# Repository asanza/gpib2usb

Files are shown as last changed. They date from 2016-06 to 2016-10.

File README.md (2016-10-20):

# GPIB (IEEE-488) to usb adapter


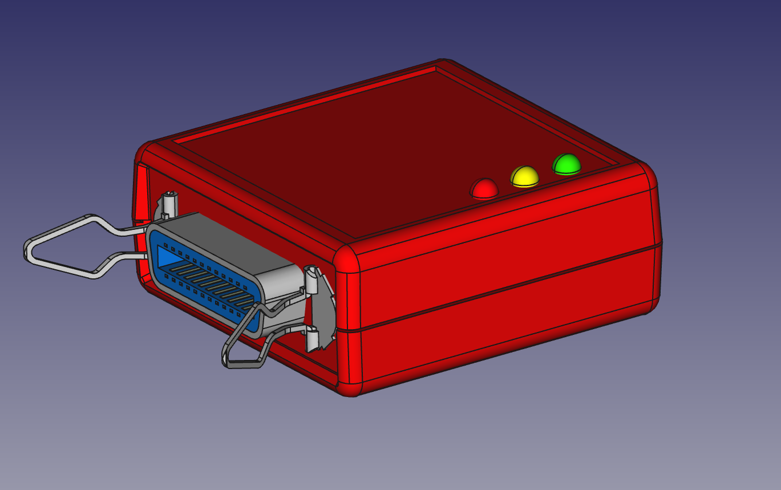
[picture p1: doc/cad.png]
gpib2usb


We live in wonderful times... Now is possible for us to get pretty good but old and used measurement equipment on e-bay, just for a few bucks. Equipment that otherwise would be out of  the hobbist leage, like 6.5 digit multimeters, oscilloscopes, signal generators... just to name a few.

These old equipment often come with a GPIB interface, which allows to control them from a computer with the corresponding GPIB connection. Regretably, computers do not come with GPIB interfaces, and the adapters available are not cheap.

Here comes this little device to rescue. It is a gpib-to-usb adapter which after connected to the computer via the almighty usb port, it presents itself as a serial port and allows to send GPIB commands to connected GPIB devices.

For now is yet a work in progress.

# Getting Started

The device presents itself as a serial port. The commands are the same as the similar device sold by [Prologix LLC](http://prologix.biz/gpib-usb-controller.html), but compatibility is not guaranteed.

| Command	 | Description |
|---|---|
|++addr 0-31|	Tell controller which device to address|
|++addr	| Query currently configured device address
|++clr	| This command sends the Selected Device Clear (SDC) message to the currently specified GPIB address. Please consult the programming manual for details on how a particular instrument responds to this message.
|++eoi 0/1|	Enable (1) or disable (0) EOI with last byte. Default is 0. This command enables or disables the assertion of the EOI signal with the last character of any command sent over GPIB port. Some instruments require EOI signal to be asserted in order to properly detect the end of a command.
|++eoi	|Query current EOI setting
|++eos 0/1/2/3	|EOS terminator — 0:CR+LF, 1:CR, 2:LF, 3:None. Default is 0. This command specifies GPIB termination characters. When data from host is received over USB, all non-escaped LF, CR and ESC characters are removed and GPIB terminators, as specified by this command, are appended before sending the data to instruments. This command does not affect data from instruments received over GPIB port.|
|++eos	|Query current EOS setting
|++ifc	|Issue interface clear. This command asserts GPIB IFC signal for 150 microseconds making the gpib2usb controller the Controller-In-Charge on the GPIB bus.
|++loc	|Return device to local mode
|++read  [eoi/char]| This command can be used to read data from an instrument until: EOI is detected or timeout expires, or A specified character is read or timeout expires, or Timeout expires. Timeout is set using the read_tmo_ms command and applies to inter-character delay, i.e., the delay since the last character was read. Timeout is not be confused with the total time for which data is read. |
|++read_tmo_ms [1-3000]| This command specifies the timeout value, in milliseconds, to be used in the read command and spoll command. Timeout may be set to any value between 1 and 3000 milliseconds.|
|++spoll	|Read status byte by serial polling the device
|++srq	|Query status of SRQ line. 0: Not asserted, 1:Asserted
|++trg	|Issue device trigger
|++ver	|Query GPIB-USB controller version
|++help	|Print help about commands

To send binary data to instruments following characters must be escaped by preceding them with an ESC character:
CR (ASCII 13), LF (ASCII 10), ESC (ASCII 27), ‘+’ (ASCII 43)

# Contributing

# Know issues

## Disable modem manager in linux.

In order to detect new devices, modem manager issues two AT commands to each new ACM device detected. This blocks the serial port and causes it to be unavailable the first seconds. This is somewhat annoying. Fortunately it is possible to disable this behaviour. You need to create a new file:

```
/etc/udev/rules.d/77-mm-usb-device-blacklist.rules
```
and put following content in it:

```
with content:
# gpib2usb converter
ATTRS{idVendor}=="1209", ATTRS{idProduct}=="0001", ENV{ID_MM_DEVICE_IGNORE}="1"
```

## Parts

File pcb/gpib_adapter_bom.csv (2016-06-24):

Id | Designator | Package | Quantity | Designation | Supplier and ref
1 | P5 | gpib_conn_male | 1 | GPIB
2 | C2,C3 | C_0805 | 2 | 18p
3 | C7,C8,C4,C5 | C_0805 | 4 | 100n
4 | R1 | R_0805 | 1 | R
5 | R2,R3 | R_0805 | 2 | 22
6 | R4,R5,R6 | R_0805 | 3 | 470
7 | U1 | SOIC-20_7.5x12.8mm_Pitch1.27mm | 1 | SN75160
8 | U2 | SOIC-20_7.5x12.8mm_Pitch1.27mm | 1 | SN75161
9 | P1 | TC2030-NL_SMALL | 1 | TC2030-MCP
10 | D4 | PRTR5V0U2X | 1 | PRTR5V0U2X
11 | F1 | R_1210 | 1 | F_Small
12 | D3,D1,D2 | LED-5MM | 3 | PWR
13 | U3 | TQFP-44_10x10mm_Pitch0.8mm | 1 | PIC18(L)F4550-I/PT
14 | X1 | Crystal_SMD_5032_4Pads | 1 | 8MHz
15 | C1 | C_0805 | 1 | 1u
16 | C6,C9 | C_0805 | 2 | 10n
17 | C10 | C_1206 | 1 | C
18 | R7 | R_1206 | 1 | R
19 | P2 | USB_B | 1 | USB

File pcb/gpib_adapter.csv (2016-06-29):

Source: | /home/diego/Projects/gpib2usb/pcb/gpib_adapter.sch
Date: | Mi 29 Jun 2016 20:20:03 CEST
Tool: | Eeschema 4.1.0-alpha+201606241232+6946~45~ubuntu16.04.1-product
Generator: | /home/diego/Electronics/Libraries/scripts/bom_csv_grouped_by_value_with_fp.py
Component Count: | 29
Ref | Qnty | Value | Cmp name | Footprint | Description | Vendor
C1, | 1 | 1u | C | Capacitors_SMD:C_0805 | Unpolarized capacitor
C3, C2, | 2 | 18p | C | Capacitors_SMD:C_0805 | Unpolarized capacitor
C6, C9, | 2 | 10n | C | Capacitors_SMD:C_0805 | Unpolarized capacitor
C7, C8, C4, C5, | 4 | 100n | C | Capacitors_SMD:C_0805 | Unpolarized capacitor
C10, | 1 | C | C | Capacitors_SMD:C_1206 | Unpolarized capacitor
D1, D2, D3, | 3 | PWR | LED-RESCUE-gpib_adapter | LEDs:LED-5MM
D4, | 1 | PRTR5V0U2X | PRTR5V0U2X | esd_protection:PRTR5V0U2X
F1, | 1 | F_Small | F_Small | Resistors_SMD:R_1210 | Fuse
P1, | 1 | TC2030-MCP | TC2030-MCP | tagconnect:TC2030-NL_SMALL
P2, | 1 | USB | CONN_5 | Connect:USB_B
P5, | 1 | GPIB | CONN_12X2 | gpib_conn_male:gpib_conn_male
R1, | 1 | R | R-RESCUE-gpib_adapter | Resistors_SMD:R_0805
R2, R3, | 2 | 22 | R | Resistors_SMD:R_0805 | Resistor
R4, R5, R6, | 3 | 470 | R | Resistors_SMD:R_0805 | Resistor
R7, | 1 | R | R | Resistors_SMD:R_1206 | Resistor
U1, | 1 | SN75160 | SN75160 | Housings_SOIC:SOIC-20_7.5x12.8mm_Pitch1.27mm
U2, | 1 | SN75161 | SN75161 | Housings_SOIC:SOIC-20_7.5x12.8mm_Pitch1.27mm
U3, | 1 | PIC18(L)F4550-I/PT | PIC18(L)F4550-I/PT | Housings_QFP:TQFP-44_10x10mm_Pitch0.8mm | PIC18(L)F4455, 24K Flash, 2K SRAM, 256 EEPROM, USB, nanoWatt XLP, TQFP44
X1, | 1 | 8MHz | CRYSTAL_SMD | Crystals:Crystal_SMD_5032_4Pads

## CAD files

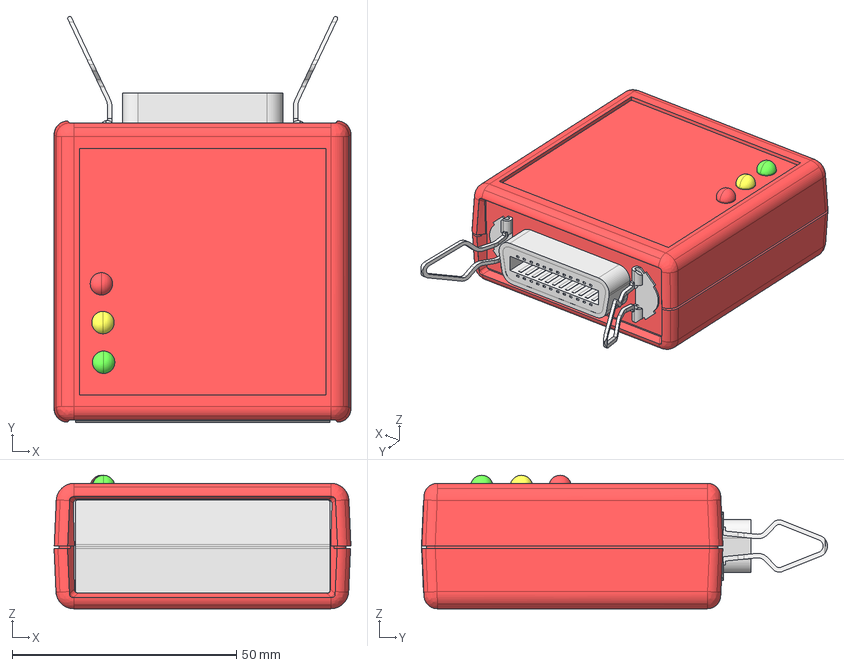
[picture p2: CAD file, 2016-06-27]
pcb/cad/assembly.fcstd
66.3 x 90.6 x 29.8 mm
_593K_BOTTOM
_593K_Endplate
_593K_Top
_593K_L_Contoured_Endplate
Board_outline
LED 5mm
LED 5mm003
LED 5mm006
Centronics

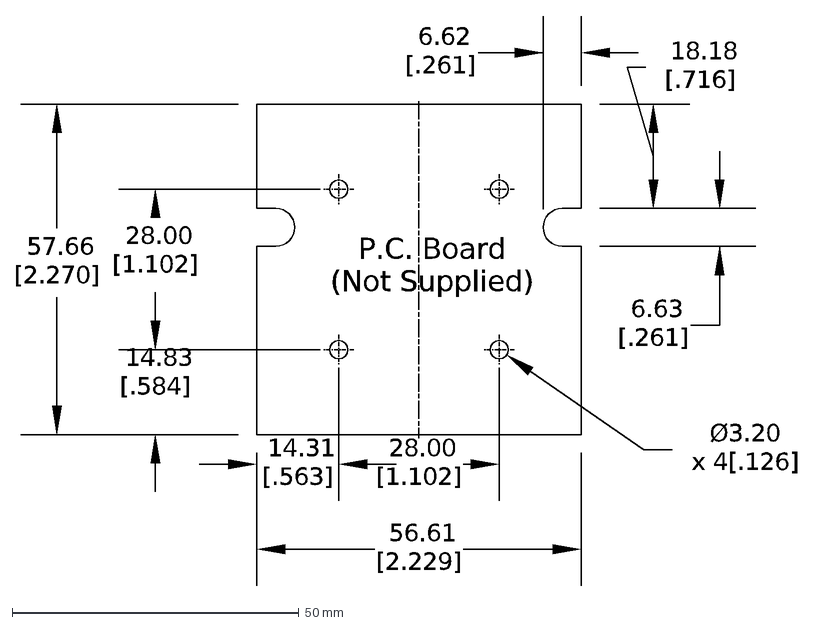
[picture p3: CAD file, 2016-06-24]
pcb/floorplan.dxf
28.00 [1.102]
56.61 [2.229]
14.31 [.563]
57.66 [2.270]
18.18 [.716]
6.63 [.261]
14.83 [.584]
6.62 [.261]
Ø3.20 x 4[.126]
P.C. Board (Not Supplied)

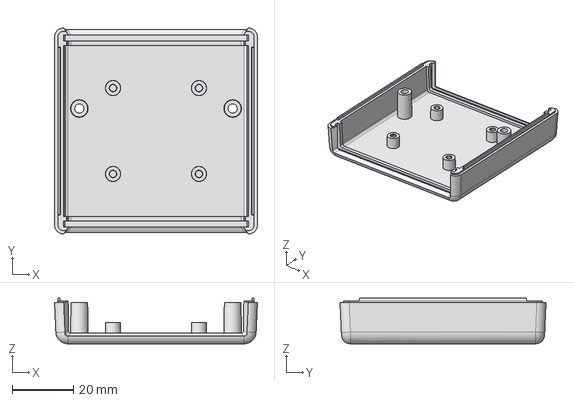
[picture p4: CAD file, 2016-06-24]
pcb/cad/1593K BOTTOM.stp
66.2 x 67.2 x 14.9 mm

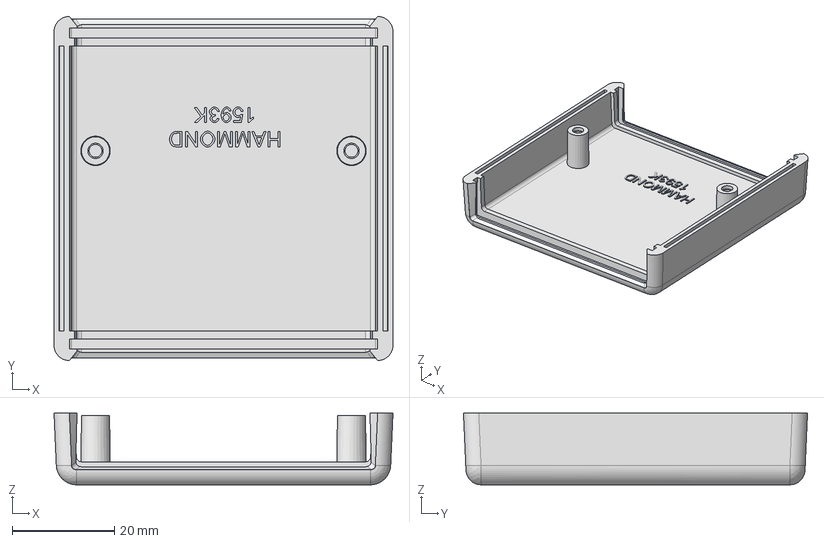
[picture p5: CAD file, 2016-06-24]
pcb/cad/1593K Top.stp
66.2 x 67.2 x 14.0 mm

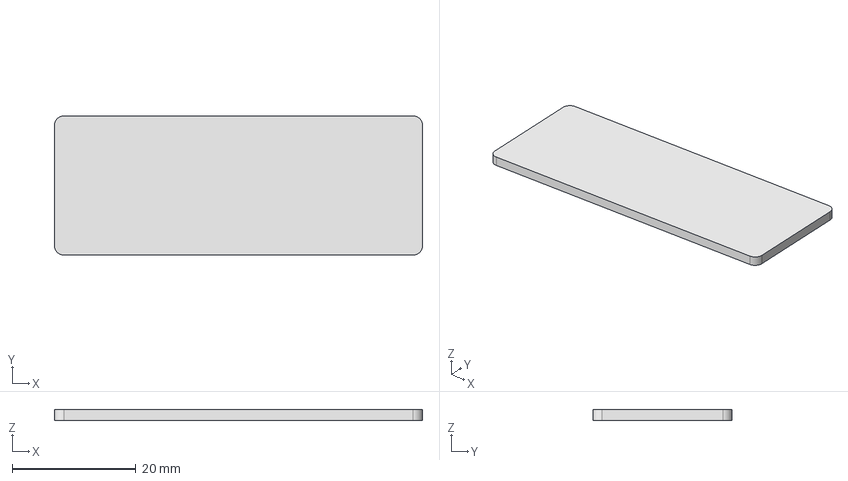
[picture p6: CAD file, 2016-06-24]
pcb/cad/1593K Endplate.stp
59.5 x 22.5 x 1.70 mm

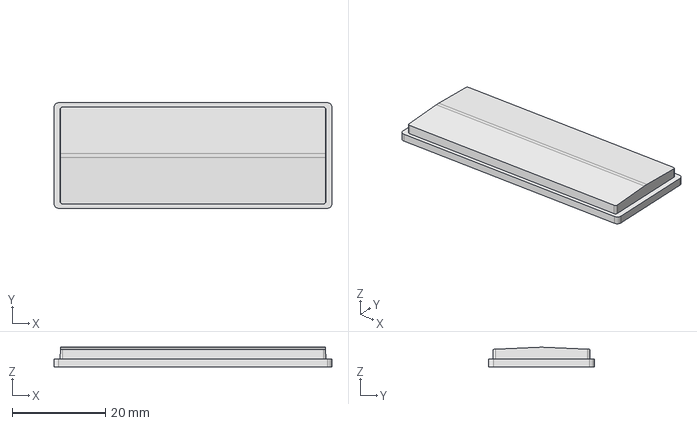
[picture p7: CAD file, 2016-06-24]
pcb/cad/1593K-L Contoured Endplate.stp
59.5 x 22.6 x 4.19 mm

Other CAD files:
pcb/cad/1593K.dwg
pcb/cad/1593K BOTTOM.igs
pcb/cad/1593K Endplate.igs
pcb/cad/1593K Top.igs
pcb/cad/1593K-L Contoured Endplate.igs

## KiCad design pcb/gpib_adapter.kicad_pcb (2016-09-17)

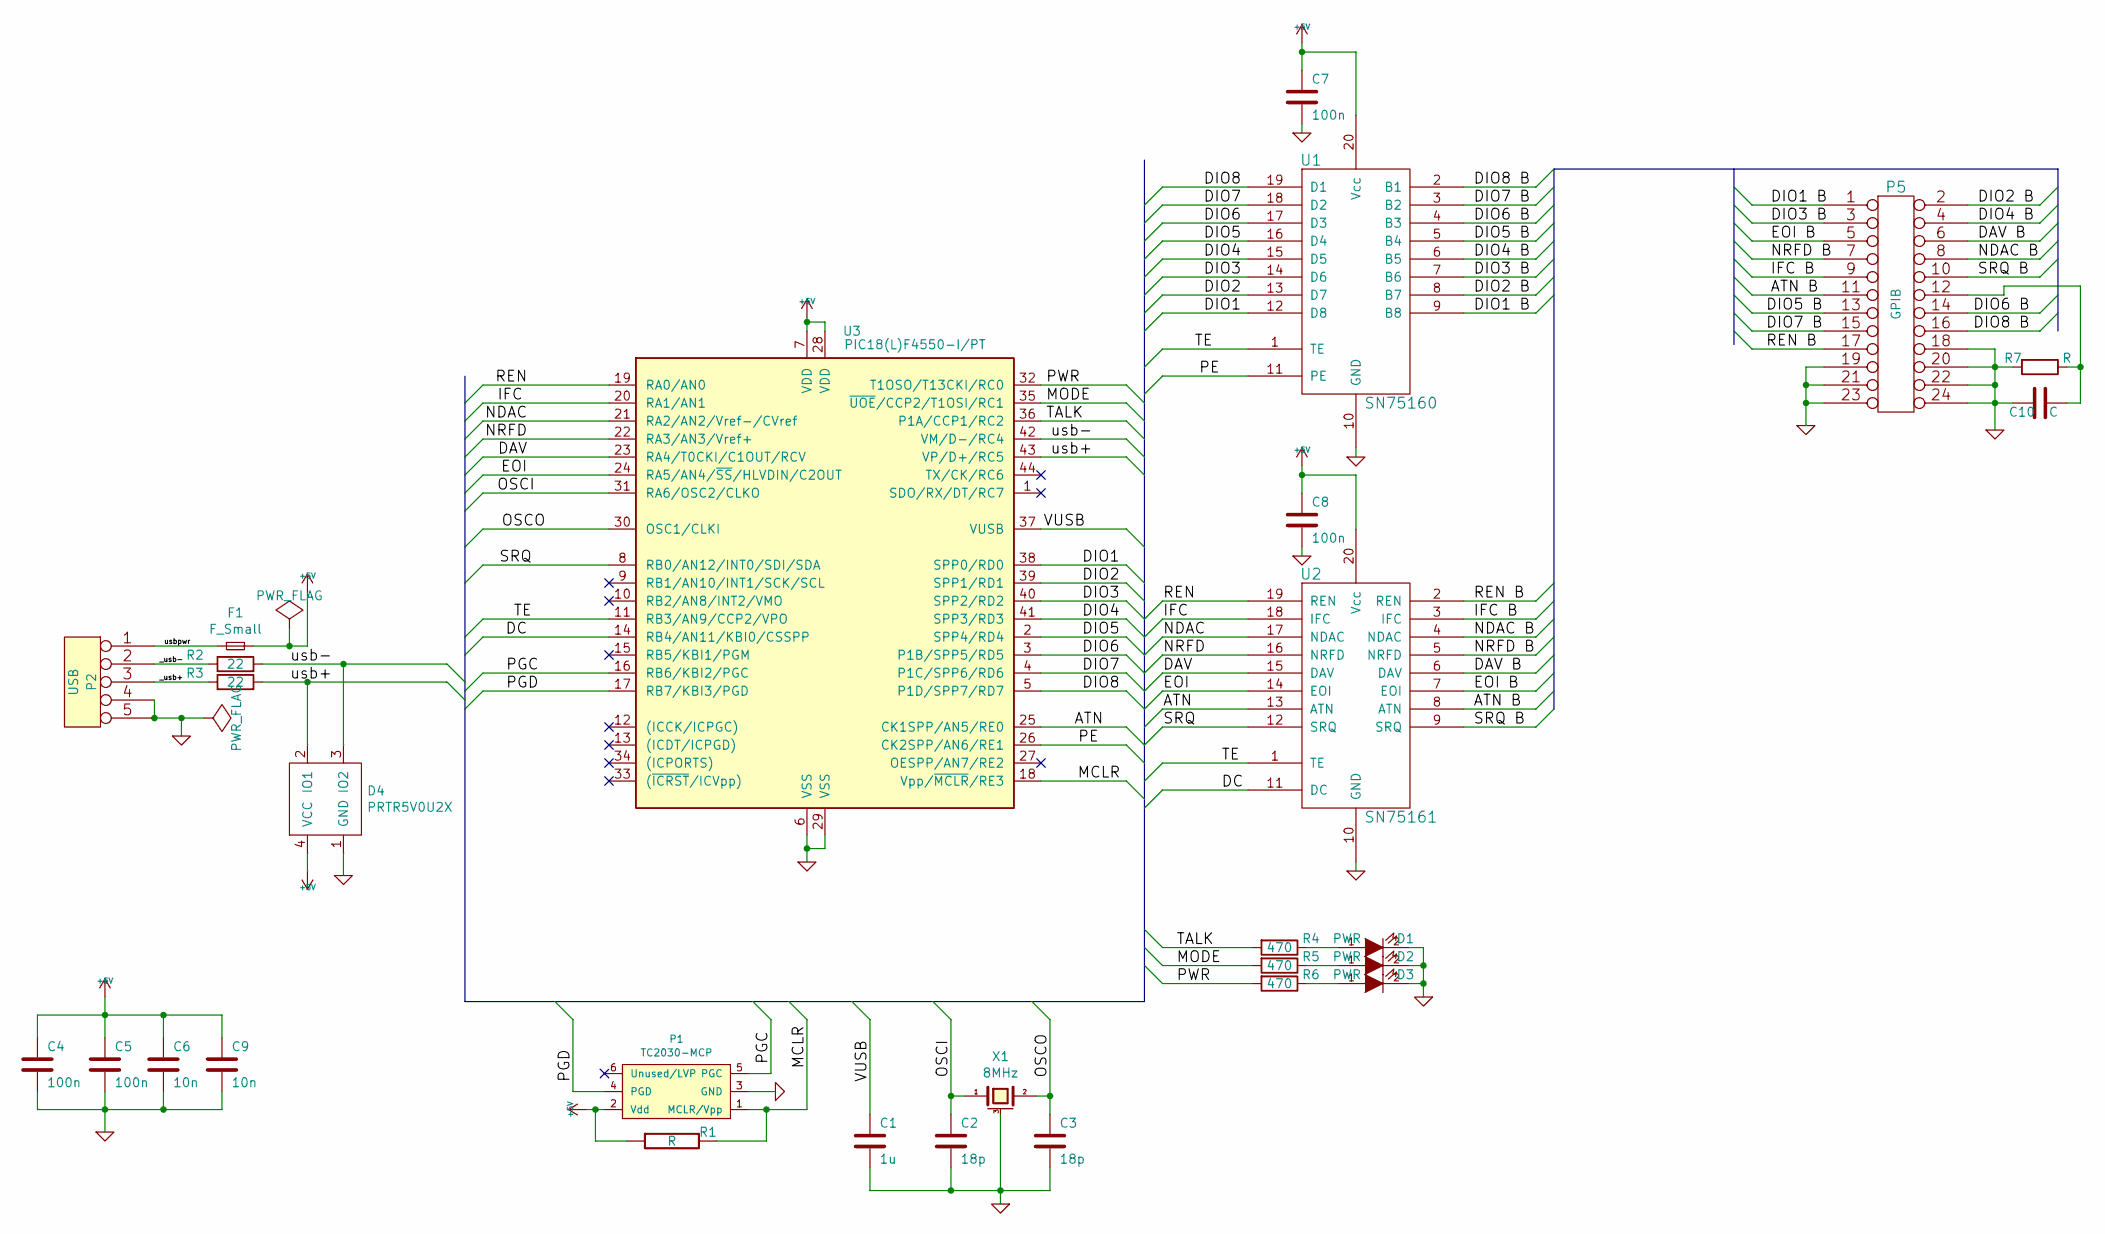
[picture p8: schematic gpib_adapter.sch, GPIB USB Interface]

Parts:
C1: 1u; C_0805
C2, C3: 18p; C_0805
C4, C5, C7, C8: 100n; C_0805
C6, C9: 10n; C_0805
C10: C; C_1206
D1, D2, D3: PWR; LED-5MM
D4: PRTR5V0U2X
F1: F_Small; R_1210
P1: TC2030-MCP; TC2030-NL_SMALL
P2: USB; USB_B
P5: GPIB; gpib_conn_male; Digikey 1024RFA-ND
R1: R; R_0805
R2, R3: 22; R_0805
R4, R5, R6: 470; R_0805
R7: R; R_1206
U1: SN75160; SOIC-20_7.5x12.8mm_Pitch1.27mm
U2: SN75161; SOIC-20_7.5x12.8mm_Pitch1.27mm
U3: PIC18(L)F4550-I/PT; TQFP-44_10x10mm_Pitch0.8mm
X1: 8MHz; Crystal_SMD_5032_4Pads

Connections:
+5V: C4.1, C5.1, C6.1, C7.1, C8.1, C9.1, D4.4 (VCC), F1.2, P1.2 (Vdd), R1.1, U1.20 (Vcc), U2.20 (Vcc), U3.7 (VDD), U3.28 (VDD)
/ATN: U2.13 (ATN), U3.25 (CK1SPP/AN5/RE0)
/ATN B: P5.11, U2.8 (ATN)
/DAV: U2.15 (DAV), U3.23 (RA4/T0CKI/C1OUT/RCV)
/DAV B: P5.6, U2.6 (DAV)
/DC: U2.11 (DC), U3.14 (RB4/AN11/KBI0/CSSPP)
/DIO1: U1.12 (D8), U3.38 (SPP0/RD0)
/DIO1 B: P5.1, U1.9 (B8)
/DIO2: U1.13 (D7), U3.39 (SPP1/RD1)
/DIO2 B: P5.2, U1.8 (B7)
/DIO3: U1.14 (D6), U3.40 (SPP2/RD2)
/DIO3 B: P5.3, U1.7 (B6)
/DIO4: U1.15 (D5), U3.41 (SPP3/RD3)
/DIO4 B: P5.4, U1.6 (B5)
/DIO5: U1.16 (D4), U3.2 (SPP4/RD4)
/DIO5 B: P5.13, U1.5 (B4)
/DIO6: U1.17 (D3), U3.3 (P1B/SPP5/RD5)
/DIO6 B: P5.14, U1.4 (B3)
/DIO7: U1.18 (D2), U3.4 (P1C/SPP6/RD6)
/DIO7 B: P5.15, U1.3 (B2)
/DIO8: U1.19 (D1), U3.5 (P1D/SPP7/RD7)
/DIO8 B: P5.16, U1.2 (B1)
/EOI: U2.14 (EOI), U3.24 (RA5/AN4/~SS~/HLVDIN/C2OUT)
/EOI B: P5.5, U2.7 (EOI)
/IFC: U2.18 (IFC), U3.20 (RA1/AN1)
/IFC B: P5.9, U2.3 (IFC)
/MCLR: P1.1 (MCLR/Vpp), R1.2, U3.18 (Vpp/~MCLR~/RE3)
/MODE: R5.2, U3.35 (~UOE~/CCP2/T1OSI/RC1)
/NDAC: U2.17 (NDAC), U3.21 (RA2/AN2/Vref-/CVref)
/NDAC B: P5.8, U2.4 (NDAC)
/NRFD: U2.16 (NRFD), U3.22 (RA3/AN3/Vref+)
/NRFD B: P5.7, U2.5 (NRFD)
/OSCI: C2.1, U3.31 (RA6/OSC2/CLKO), X1.1
/OSCO: C3.1, U3.30 (OSC1/CLKI), X1.2
/PE: U1.11 (PE), U3.26 (CK2SPP/AN6/RE1)
/PGC: P1.5 (PGC), U3.16 (RB6/KBI2/PGC)
/PGD: P1.4 (PGD), U3.17 (RB7/KBI3/PGD)
/PWR: R6.2, U3.32 (T1OSO/T13CKI/RC0)
/REN: U2.19 (REN), U3.19 (RA0/AN0)
/REN B: P5.17, U2.2 (REN)
/SRQ: U2.12 (SRQ), U3.8 (RB0/AN12/INT0/SDI/SDA)
/SRQ B: P5.10, U2.9 (SRQ)
/TALK: R4.2, U3.36 (P1A/CCP1/RC2)
/TE: U1.1 (TE), U2.1 (TE), U3.11 (RB3/AN9/CCP2/VPO)
/VUSB: C1.1, U3.37 (VUSB)
/_usb+: P2.3, R3.1
/_usb-: P2.2, R2.1
/usb+: D4.2 (IO1), R3.2, U3.43 (VP/D+/RC5)
/usb-: D4.3 (IO2), R2.2, U3.42 (VM/D-/RC4)
/usbpwr: F1.1, P2.1
GND: C1.2, C2.2, C3.2, C4.2, C5.2, C6.2, C7.2, C8.2, C9.2, C10.2, D1.2 (K), D2.2 (K), D3.2 (K), D4.1 (GND), P1.3 (GND), P2.4, P2.5, P5.18, P5.19, P5.20, P5.21, P5.22, P5.23, P5.24, R7.2, U1.10 (GND), U2.10 (GND), U3.6 (VSS), U3.29 (VSS), X1.3 (case)
unnamed: C10.1, P5.12, R7.1
unnamed: D1.1 (A), R4.1
unnamed: D2.1 (A), R5.1
unnamed: D3.1 (A), R6.1

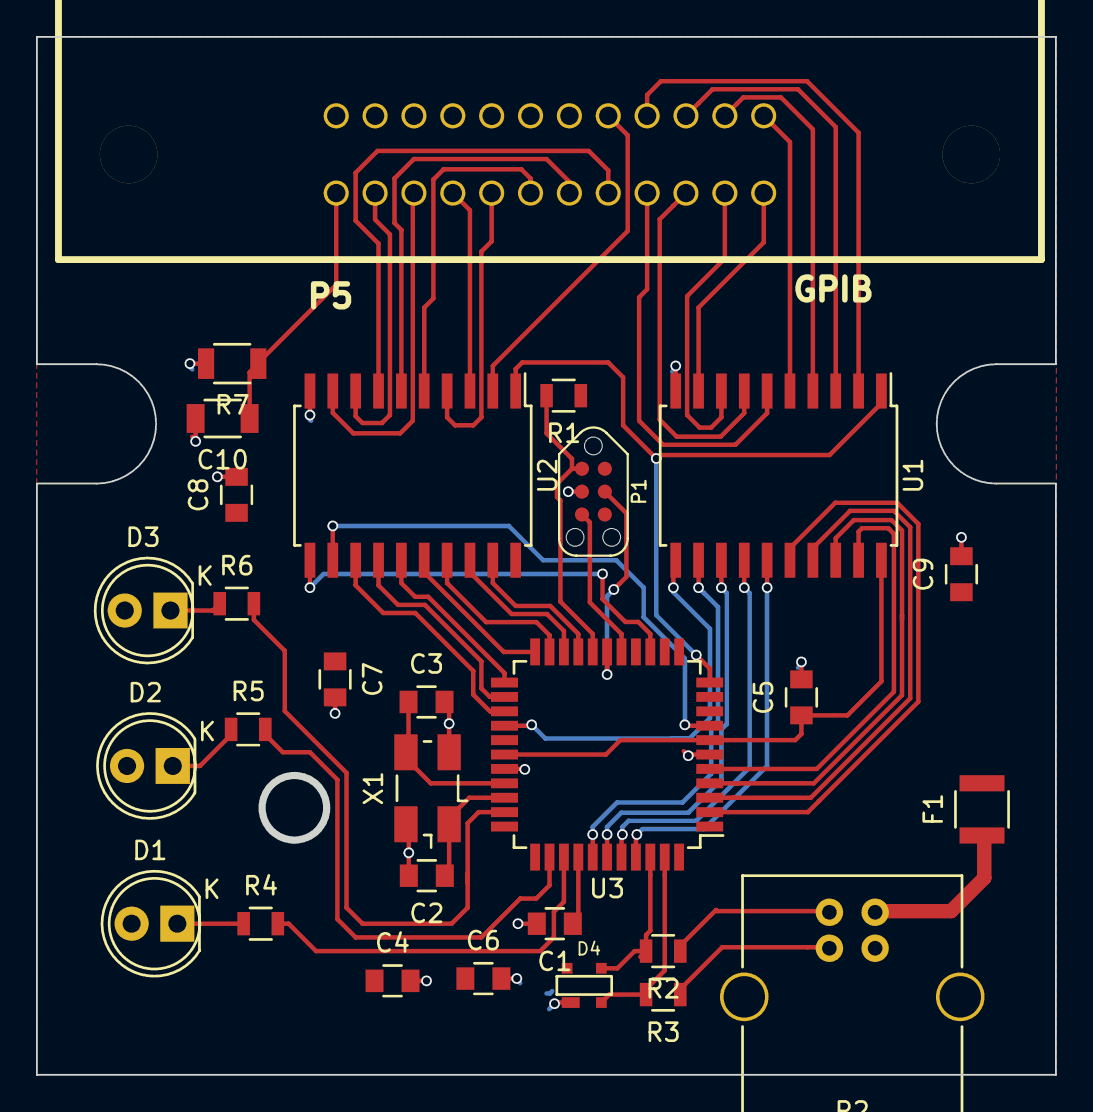
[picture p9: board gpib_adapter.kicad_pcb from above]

Board: 2 copper layers, 56.6 x 57.7 mm, 29 parts (0 on the bottom side), 55 nets.

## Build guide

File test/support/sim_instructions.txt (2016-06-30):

device pic18f4550
hwtool sim
set oscillator.frequency 	8
set oscillator.frequencyunit 	Mega
set oscillator.rcfrequency  	250
set oscillator.rcfrequencyunit 	Kilo
set uart1io.uartioenabled	true
set uart1io.output		file
set uart1io.outputfile		test/support/out.txt
set system.disableerrormsg 	true
set breakoptions.coreerrors 	Break
set breakoptions.peripheralerrors Break
set breakoptions.wdtwarnings 	Break
set breakoptions.peripheralwarnings Break

program build/test/TestBuild.elf

run
break unity.c:1168
wait 5000
quit

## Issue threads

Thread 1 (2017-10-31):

Produced no output to $stdout.

Neroone, 2017-10-31:
Hi,

I am new to PIC microcontrollers and I am trying to write unit tests for PIC18F86K22.  I use a xc8 compiler. I found your project using a PIC and xc8 compiler while browsing. I am trying to use ceedling and I have tried to use some of your files and added a simple c file and test file. When I run ceedling test:all on Ubuntu 16.04, I get the following error.
ERROR: Test executable "test_lights.out" failed.
> Produced no output to $stdout.
> And exited with status: [0] (count of failed tests).
> This is often a symptom of a bad memory access in source or test code. and no out.txt is created. Also, in simlog.txt I notice that the program has failed. Can you please help me figure out why I get this error.
Thanks.
[testproject.zip](https://github.com/asanza/gpib2usb/files/1431758/testproject.zip)

asanza, 2017-10-31:
Hi,
I think you test are compiling just fine, they are just not being executed.

Looking into the log of the test fixture (test/support/simlog.txt), it seems that your simulator is not loading the firmware, but I cannot figure out why.
```
program build/test/TestBuild.elf
Programming target...
Program failed.
```
Could you just check that the TestBuild.elf file exists, and try to load it manually in the mplab simulator,
may be give you more clues.

Neroone, 2017-11-01:
Hi,
The testBuild.elf does exist and I tried running from the mdb command line. The program was not executed.

I tried changing the .elf to .hex in sim_instructions.txt and the out.txt was created this time(with some garbled letters).
and simlog.txt had the following
program build/test/TestBuild.hex
Programming target...
Program succeeded.
run

break unity.c:1168
unity.c:1168 could not be resolved to an address
wait 5000
quit
Stop at
	address:0xf0e2

I am still getting the error from ceedling:test all

ERROR: Test executable "test_lights.out" failed.
> Produced no output to $stdout.
> And exited with status: [0] (count of failed tests).
> This is often a symptom of a bad memory access in source or test code.

Any suggestions?

asanza, 2017-11-04:
Hi,
Yes a couple of points:

1. break unity.c:1168 was an ugly hack in order to exit the simulator when unity exits.
I couldn't figure out other way.  You can look where is the exit line in your unity.c and
locate the breakpoint there.

2. Unity (and ceedling) work printing the unit tests data to stdout (which in the microcontroller, or simulator is the serial port.) The file sim_instructions.txt contain following line:
```
set uart1io.outputfile		test/support/out.txt
```
Which is a specific configuration for the processor I am using. You should check that the simulator supports uart1io for your processor. (look mplabx settings).

Also the processor should be configured in order to redirect stdout to the serial port for the printf functions to work. I did that in the files support_uart.c. There are two functions, first the putchar function that is needed for stdout redirection ( I don't remember if there is other thing you need, so check it in the stdout redirection section of the compiler documentation), and the init_uart function which configures the processor registers. This Init_uart should be called after each test (in thet setUp functions).

Neroone, 2017-11-09:
Thank you so much for your help.
I was able to it to program the target. My extended instruction set had to
be turned off. So that works. I am not able to get the UART output.

1. The PIC18F86K22 does have two UARTs. and I run it on Ubuntu 16.04.

So the lines
set uart1io.uartioenabled true
set uart1io.output         file
set uart1io.outputfile test/support/out.txt seems correct.

2. I have impllemented both putch() and support_init_uart() *code for
support_uart.c file* that I modified for my PIC.

void putch(char data)
{
while ( !TXIF)
continue;
TXREG = data;
}

*3. When I run ceedling test:all I get the error*

*ERROR: Test executable "test_lights.out" failed.*
> *Produced no output to $stdout.*
> And exited with status: [0] (count of failed tests).
> This is often a symptom of a bad memory access in source or test code.

Now the *out.txt shows up* and I only use TestBuild.elf now and is
populated but I get no test summary on the command line and rake is aborted.

*4. And when I look at the simlog.txt I see the following error message.*

break unity.c:1184
unity.c:1184 could not be resolved to an address
wait 5000

quit
Stop at
address:0xf0c0
file:/home/usha/Software/SoftVueTest4/test/support/support_uart.c
source line:59

*The line 59 is while ( !TXIF).*

I am not able to figure out what is failing now as there is no output on
the command line with the Test Summary. I have also attached all the files
that I am using.

*Thanks again,*
*Usha*

On Sat, Nov 4, 2017 at 1:48 PM, Diego Asanza <notifications@github.com>
wrote:

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

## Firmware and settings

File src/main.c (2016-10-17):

/*
 * USB CDC-ACM Demo
 *
 * This file may be used by anyone for any purpose and may be used as a
 * starting point making your own application using M-Stack.
 *
 * It is worth noting that M-Stack itself is not under the same license as
 * this file.
 *
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
 * Alan Ott
 * Signal 11 Software
 * 2014-05-12
 */

#include "usb.h"
#include "hal/hal_sys.h"
#include "hal/hal_timer.h"
#include "sys/sysio.h"
#include "sys/system.h"
#include "gpib/gpib.h"
#include <string.h>
#include "usb_config.h"
#include "usb_ch9.h"
#include "usb_cdc.h"
#include <assert.h>

#include <stdio.h>
#include "hal/hal_uart.h"

#ifdef MULTI_CLASS_DEVICE
static uint8_t cdc_interfaces[] = { 0 };
#endif

static void send_string_sync(uint8_t endpoint, const char *str)
{
	char *in_buf = (char*)usb_get_in_buffer(endpoint);

	while (usb_in_endpoint_busy(endpoint)) ;

	strcpy(in_buf, str);
	/* Hack: Get the length from strlen(). This is inefficient, but it's
	 * just a demo. strlen()'s return excludes the terminating NULL. */
	usb_send_in_buffer(endpoint, strlen(in_buf));
}

static void write_buffer_sync(const char* str, int len)
{
	char *in_buf = (char*)usb_get_in_buffer(2);
	while (usb_in_endpoint_busy(2)) ;
	strncpy(in_buf, str, len);
	usb_send_in_buffer(2, len);
}

static void write_char_sync(const char c)
{
	write_buffer_sync(&c, 1);
}

int main(void)
{
	char* input;
	int len;
	hal_sys_init();
	sys_init();
#ifdef MULTI_CLASS_DEVICE
	cdc_set_interface_list(cdc_interfaces, sizeof(cdc_interfaces));
#endif
	usb_init();
	while (1) {
		if (!usb_is_configured()) continue;
		switch (sysio_get_state()) {
		case SYSIO_EMPTY: break;
		case SYSIO_DATA_AVAILABLE:         /* data */
			hal_sys_green_led_toggle();
			sysio_release();
			break;
		case SYSIO_CMD_AVAILABLE:         /* cmd  */
			len = sysio_get_buffer(&input);
			len = sys_process_command(input, len);
			if(len != 0){
				write_buffer_sync(input, len);
			}
			sysio_release();
			break;
		}
	}
	return 0;
}



/* Callbacks. These function names are set in usb_config.h. */
void app_set_configuration_callback(uint8_t configuration)
{
}

uint16_t app_get_device_status_callback()
{
	return 0x0000;
}

void app_endpoint_halt_callback(uint8_t endpoint, bool halted)
{

}

int8_t app_set_interface_callback(uint8_t interface, uint8_t alt_setting)
{
	return 0;
}

int8_t app_get_interface_callback(uint8_t interface)
{
	return 0;
}

void app_out_transaction_callback(uint8_t endpoint)
{
	char* out_buf;
	char* in_buf;
	int len;
	if(!usb_is_configured())
		return;
	if(!usb_out_endpoint_has_data(2))
		return;
 	in_buf = (char*)usb_get_in_buffer(2);
	len = usb_get_out_buffer(2, &out_buf);
	len = sysio_data_received(out_buf, len);
	if(len){
		strncpy(in_buf, out_buf, len);
		usb_send_in_buffer(2, len);
	}
	usb_arm_out_endpoint(2);
}

void app_in_transaction_complete_callback(uint8_t endpoint)
{

}

int8_t app_unknown_setup_request_callback(const struct setup_packet *setup)
{
	/* To use the CDC device class, have a handler for unknown setup
	 * requests and call process_cdc_setup_request() (as shown here),
	 * which will check if the setup request is CDC-related, and will
	 * call the CDC application callbacks defined in usb_cdc.h. For
	 * composite devices containing other device classes, make sure
	 * MULTI_CLASS_DEVICE is defined in usb_config.h and call all
	 * appropriate device class setup request functions here.
	 */
	return process_cdc_setup_request(setup);
}

int16_t app_unknown_get_descriptor_callback(const struct setup_packet *pkt, const void **descriptor)
{
	return -1;
}

void app_start_of_frame_callback(void)
{

}

void app_usb_reset_callback(void)
{
}

/* CDC Callbacks. See usb_cdc.h for documentation. */

int8_t app_send_encapsulated_command(uint8_t interface, uint16_t length)
{
	return -1;
}

int16_t app_get_encapsulated_response(uint8_t interface,
				      uint16_t length, const void **report,
				      usb_ep0_data_stage_callback *callback,
				      void **context)
{
	return -1;
}

void app_set_comm_feature_callback(uint8_t interface,
				   bool idle_setting,
				   bool data_multiplexed_state)
{
}

void app_clear_comm_feature_callback(uint8_t interface,
				     bool idle_setting,
				     bool data_multiplexed_state)
{
}

int8_t app_get_comm_feature_callback(uint8_t interface,
				     bool *idle_setting,
				     bool *data_multiplexed_state)
{
	return -1;
}

void app_set_line_coding_callback(uint8_t interface,
				  const struct cdc_line_coding *coding)
{
}

int8_t app_get_line_coding_callback(uint8_t interface,
				    struct cdc_line_coding *coding)
{
	/* This is where baud rate, data, stop, and parity bits are set. */
	return -1;
}

int8_t app_set_control_line_state_callback(uint8_t interface,
					   bool dtr, bool dts)
{
	return 0;
}

int8_t app_send_break_callback(uint8_t interface, uint16_t duration)
{
	return 0;
}


void interrupt high_priority isr()
{
	usb_service();
}

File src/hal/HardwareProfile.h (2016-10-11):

#ifndef _HARDWAREPROFILE_H_
#define _HARDWAREPROFILE_H_

#include <xc.h>

#define BIT0 0x00
#define BIT1 0x01
#define BIT2 0x02
#define BIT3 0x03
#define BIT4 0x04
#define BIT5 0x05
#define BIT6 0x06
#define BIT7 0x07

#define _BV(val) (1 << val);

/* define pins, Format: PORT NAME, PIN NAME*/

/* data port */
#define _DIO D
#define _PE E, BIT1
#define _TE_DATA B, BIT3
/* bus management lines */
#define _ATN E, BIT0
#define _IFC A, BIT1
#define _REN A, BIT0
#define _EOI A, BIT5
#define _SRQ B, BIT0
/* talker enable for control */
#define _TE_CTRL B, BIT3
/* data direction control */
#define _DC B, BIT4

/* bus handshake lines */
#define _DAV A, BIT4
#define _NRFD A, BIT3
#define _NDAC A, BIT2

/* LEDS */
#define GREEN_LED   C, BIT2
#define YELLOW_LED  C, BIT1
#define RED_LED     C, BIT0

/* Auxiliary macros */
#define PinAsInput(val)        _PinAsInput(val)
#define PinAsOutput(val)       _PinAsOutput(val)
#define PinSetValue(val)        _PinSetValue(val)
#define PinClearValue(val)      _PinClearValue(val)
#define PinToggleValue(val)     _PinToggleValue(val)
#define PinReadValue(val)       _PinReadValue(val)
#define PinDirection(val)               _PinDirection(val)

#define PortAsInput(val)       _PortAsInput(val)
#define PortAsOutput(val)      _PortAsOutput(val)
#define PortDirection(val)         _PortDirection(val)
#define PortSetValue(port, val)       _PortSetValue(port, val)
#define PortReadValue(port)      _PortReadValue(port)

#define _PinAsInput(port, pin) TRIS ## port |= _BV(pin)
#define _PinAsOutput(port, pin) TRIS ## port &= ~_BV(pin)
#define _PinToggleValue(port, pin) LAT ## port ^= _BV(pin)
#define _PinSetValue(port, pin) LAT ## port |= _BV(pin)
#define _PinClearValue(port, pin) LAT ## port &= ~_BV(pin)
#define _PinReadValue(port, pin) PORT ## port & _BV(pin)
#define _PinDirection(port, pin) TRIS ## port &= _BV(pin)

#define _PortAsInput(port) TRIS ## port = 0x00
#define _PortAsOutput(port) TRIS ## port = 0xFF
#define _PortSetValue(port, value) LAT ## port = value
#define _PortReadValue(port) PORT ## port
#define _PortDirection(port) TRIS ## port


#endif /*_HARDWAREPROFILE_H_*/

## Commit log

2015-09-12 change processor
    [gpib_adapter.sch]
2015-09-14 adding some code
    [gpib_adapter.brd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]
2015-09-23 added unit test framework
2015-10-10 changing project structure
    [gpib_adapter.sch]
2015-10-10 - change api for input functions. fix broken tests
    [main.c]
2015-10-10 fix hardware issues
    [gpib_adapter.sch]
2015-10-10 fix: fix gpib adapter connections
    [gpib_adapter-B_Cu.gbr, gpib_adapter-B_Mask.gbr, gpib_adapter-B_SilkS.gbr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]
2015-10-11 - fix: AVR should write to PORT registers and read from PIN registers.
    [HardwareProfile.h, hal_gpib.c, hal_gpib.h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]
2015-12-01 updating hardware
    [gpib_adapter-B_Cu.gbr, gpib_adapter-B_Mask.gbr, gpib_adapter-B_SilkS.gbr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]
2015-12-04 refactor driver mode function
2015-12-04 fix pin definitions
2015-12-04 invert data lines. All gpib works with inverted logic
    [hal_gpib.c, main.c]
2015-12-05 add timer files
2016-06-22 change microcontroller to pic18F to save costs
    [gpib_adapter.sch]
2016-06-22 add enclosure drawing
    [1593K.dwg, gpib_adapter.kicad_pcb, gpib_adapter.sch]
2016-06-24 Update pcb files. New version based on pic 18f4550.
    [1593K BOTTOM.igs, 1593K BOTTOM.stp, 1593K Endplate.igs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]
2016-06-24 change srq to pin rb0 to make it use the external interrupt 0
    [1593K.dwg, gpib_adapter.kicad_pcb, gpib_adapter.sch]
2016-06-25 update cad files
    [assembly.fcstd, gpib_adapter.kicad_pcb]
2016-06-25 updated cad files
    [assembly.fcstd]
2016-06-27 update documentation
    [assembly.fcstd]
2016-06-29 importing pic18f4550 software
    [gpib_adapter-B.Cu.gbr, gpib_adapter-B.Mask.gbr, gpib_adapter-B.SilkS.gbr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]
2016-07-09 add uart for debugging
2016-09-08 fix led color issues
    [HardwareProfile.h, hal_sys.c, main.c]
2016-09-11 add tx and rx error return codes
    [gpib.c]
2016-09-17 add unit tests
    [gpib_adapter.kicad_pcb]
2016-10-06 fixed version, new api
    [main.c]
2016-10-09 move usb task to timer interrupt in order to move gpib functions to blocking api
2016-10-10 working usb timers
2016-10-11 revert back to blocking gpib functions
    [gpib.c]

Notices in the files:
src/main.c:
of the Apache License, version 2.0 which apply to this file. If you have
